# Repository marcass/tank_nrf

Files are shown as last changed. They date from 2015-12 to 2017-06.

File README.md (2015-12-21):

# tank_nrf
Arduino, NRF and ultrasonic sensors

Resources:
* http://tmrh20.github.io/RF24Mesh/
* http://www.mysensors.org/
* https://bitbucket.org/teckel12/arduino-new-ping/wiki/Home
* http://www.gammon.com.au/forum/?id=12821 this is paowering using a capacitor/solar panel

Hardware:
* http://www.aliexpress.com/item/SINMAX-8dBi-Wifi-Antenna-IEEE-802-11b-g-Indoor-Parabolic-Antenna-2-4GHz-High-Gain-USB/848558663.html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,searchweb201644_3_79_78_77_82_80_62,searchweb201560_5
* nrf modules like NRF24L01+PA+LNA
* http://www.aliexpress.com/item/J34-Free-Shipping-DC-5V-Ultrasonic-Module-Distance-Measuring-Transducer-Sensor-Perfect-Waterproof/32400424410.html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,searchweb201644_3_79_78_77_82_80_62,searchweb201560_5

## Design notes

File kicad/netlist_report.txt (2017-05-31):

Info: Reading netlist file "/home/mw/Dropbox/tank_nrf/tank_nrf.net".

Info: Using references to match components and footprints.

Error: Component 'IC1' footprint 'QFN_MLF20' was not found in any libraries in the footprint library table.

Error: Component 'S1' footprint 'MODULE' was not found in any libraries in the footprint library table.

Error: Component 'U3' footprint 'MODULE' was not found in any libraries in the footprint library table.

Error: Component 'U1' footprint 'DIL20' was not found in any libraries in the footprint library table.

Error: No footprint defined for component 'D2'.

Error: No footprint defined for component 'C6'.

Error: No footprint defined for component 'Q1'.

Error: No footprint defined for component 'R3'.

Error: No footprint defined for component 'R4'.

Error: No footprint defined for component 'R2'.

Error: No footprint defined for component 'C5'.

Error: No footprint defined for component 'C4'.

Error: No footprint defined for component 'D3'.

Error: No footprint defined for component 'D1'.

Error: No footprint defined for component 'R1'.

Error: No footprint defined for component 'U2'.

Error: No footprint defined for component 'C3'.

Error: No footprint defined for component 'C2'.

Error: No footprint defined for component 'C1'.

Info: Checking netlist component footprint "C1:/58072D95:".

Error: Cannot add new component "C1:/58072D95" due to missing footprint "".

Info: Checking netlist component footprint "C2:/58072F63:".

Error: Cannot add new component "C2:/58072F63" due to missing footprint "".

Info: Checking netlist component footprint "C3:/580730B1:".

Error: Cannot add new component "C3:/580730B1" due to missing footprint "".

Info: Checking netlist component footprint "C4:/580804F8:".

Error: Cannot add new component "C4:/580804F8" due to missing footprint "".

Info: Checking netlist component footprint "C5:/58080AA5:".

Error: Cannot add new component "C5:/58080AA5" due to missing footprint "".

Info: Checking netlist component footprint "C6:/5808138D:".

Error: Cannot add new component "C6:/5808138D" due to missing footprint "".

Info: Checking netlist component footprint "D1:/5807FD29:".

Error: Cannot add new component "D1:/5807FD29" due to missing footprint "".

Info: Checking netlist component footprint "D2:/5807FDC4:".

Error: Cannot add new component "D2:/5807FDC4" due to missing footprint "".

Info: Checking netlist component footprint "D3:/58080422:".

Error: Cannot add new component "D3:/58080422" due to missing footprint "".

Info: Checking netlist component footprint "IC1:/58080884:QFN_MLF20".

Error: Cannot add new component "IC1:/58080884" due to missing footprint "QFN_MLF20".

Info: Checking netlist component footprint "Q1:/58081893:".

Error: Cannot add new component "Q1:/58081893" due to missing footprint "".

Info: Checking netlist component footprint "R1:/5807FCB2:".

Error: Cannot add new component "R1:/5807FCB2" due to missing footprint "".

Info: Checking netlist component footprint "R2:/58080B65:".

Error: Cannot add new component "R2:/58080B65" due to missing footprint "".

Info: Checking netlist component footprint "R3:/580816BC:".

Error: Cannot add new component "R3:/580816BC" due to missing footprint "".

Info: Checking netlist component footprint "R4:/5808161B:".

Error: Cannot add new component "R4:/5808161B" due to missing footprint "".

Info: Checking netlist component footprint "S1:/580734B0:MODULE".

Error: Cannot add new component "S1:/580734B0" due to missing footprint "MODULE".

Info: Checking netlist component footprint "U1:/58072C84:DIL20".

Error: Cannot add new component "U1:/58072C84" due to missing footprint "DIL20".

Info: Checking netlist component footprint "U2:/58073E5F:".

Error: Cannot add new component "U2:/58073E5F" due to missing footprint "".

Info: Checking netlist component footprint "U3:/580738E6:MODULE".

Error: Cannot add new component "U3:/580738E6" due to missing footprint "MODULE".

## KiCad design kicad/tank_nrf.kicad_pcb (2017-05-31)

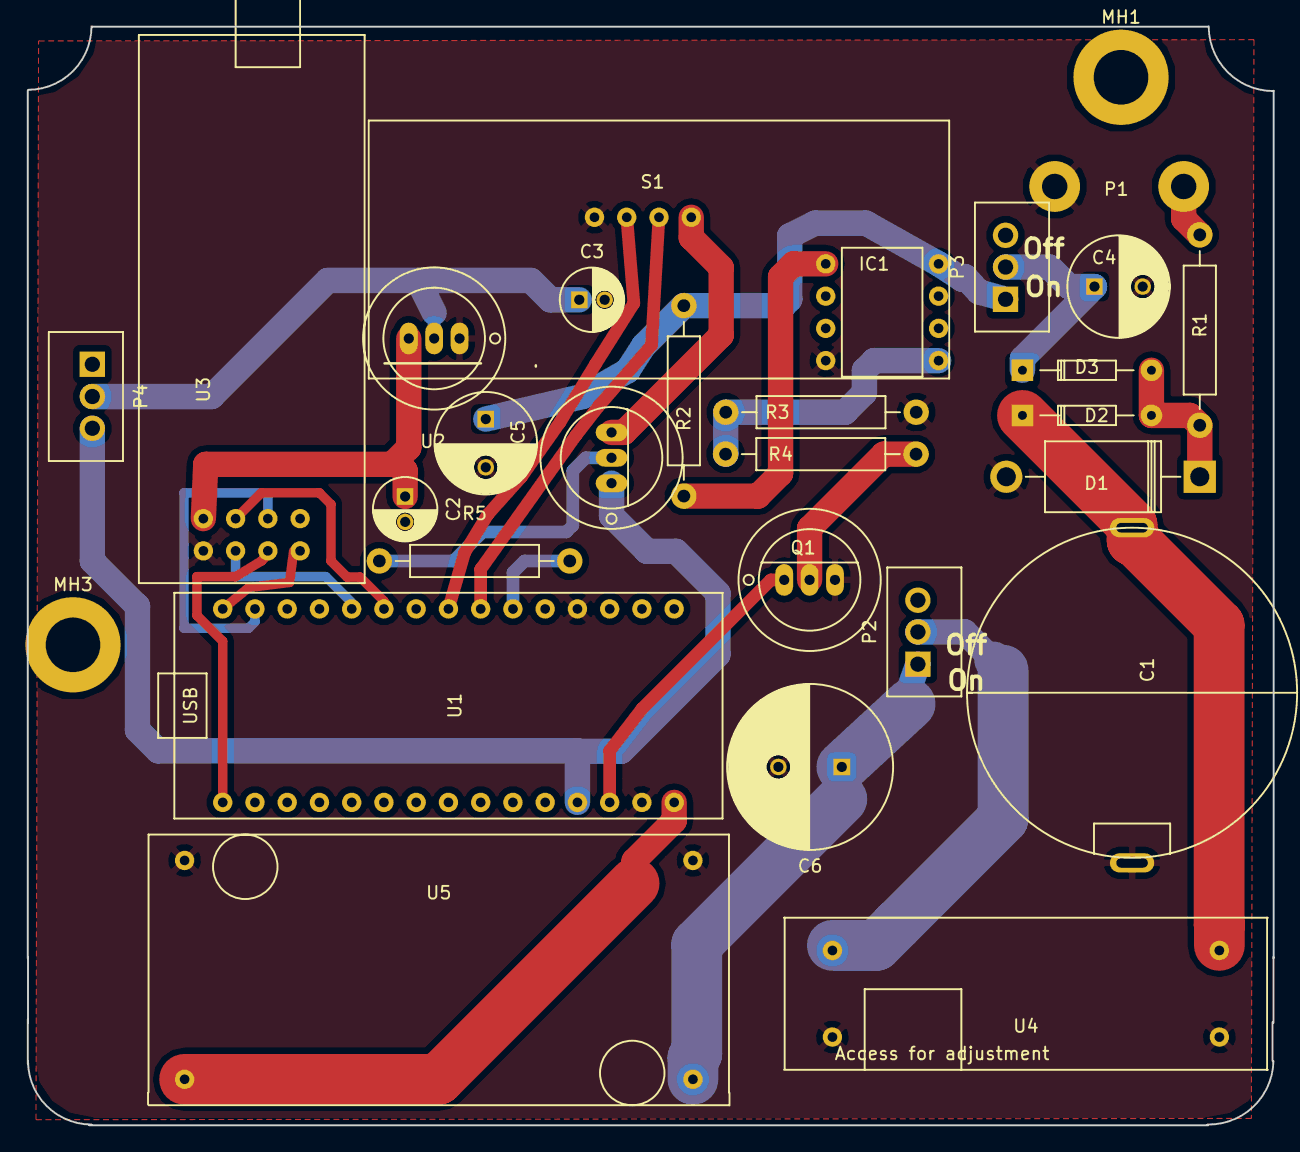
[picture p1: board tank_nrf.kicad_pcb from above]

Board: 2 copper layers, 98.1 x 86.6 mm, 29 parts (0 on the bottom side), 26 nets.

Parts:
C1: 4F; 4FCap
C2, C3: 1muF; C_Radial_D5_L11_P2
C4: 440muF; C_Radial_D8_L21_P3.8
C5: 440uF; C_Radial_D8_L13_P3.8
C6: 2F; C_Radial_D13_L21_P5
D1: 1N5817 (prev IN752); Diode_DO-201AD_Horizontal_RM15
D2, D3: IN4148; Diode_DO-35_SOD27_Horizontal_RM10
IC1: ATTINY25-SS; ATTiny85
MH1, MH3: CONN_01X01; MountingHole_4.3mm_M4_DIN965_Pad
P1: CONN_01X02; WireConnection_2.00mmDrill
P2: Jumper1; Wafer_Vertical10x5.8x7RM2.5-3
P3: Jumper2; Wafer_Vertical10x5.8x7RM2.5-3
P4: Jumper3; Wafer_Vertical10x5.8x7RM2.5-3
Q1: 2N7000
Q3: PN2222A; OldSowjetaera_Transistor_Type-I_BigPads
R1: 220; Resistor_Horizontal_RM15mm
R2, R3: 10k; Resistor_Horizontal_RM15mm
R4: 150; Resistor_Horizontal_RM15mm
R5: 470; Resistor_Horizontal_RM15mm
S1: JSN-SR40T; JSN-SR04T
U1: arduino_nano (mini?); ArduinoNano
U2: MCP1700T-3002E/TT; OldSowjetaera_Transistor_Type-I_BigPads
U3: nRF24L01+; nrf
U4: MT3608b; MT3608
U5: LM2596b; LM2596

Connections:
+5V: P4.3, Q3.1, U1.12
ATtiny5V: C5.1, IC1.8, P3.1, R2.2
CE: U1.26, U3.3
CS: U1.25, U3.4
Echo: S1.3, U1.23
GND: C1.2, C2.2, C3.2, C4.2, C5.2, C6.2, D1.2, IC1.4, P1.1, Q1.2, R3.2, S1.4, U1.14, U1.19, U2.1, U3.1, U4.2, U4.3, U5.2, U5.3
LM2596+: U1.15, U5.4
MISO: U1.30, U3.7
MOSI: U1.29, U3.6
NanoReset: Q1.3, U1.13
unnamed: C2.1, U2.3, U3.2
unnamed: C3.1, P4.2, U2.2
unnamed: C4.1, D3.1, P3.2
unnamed: C6.1, P2.1, U5.1
unnamed: D1.1, D2.2, D3.2, R1.2
unnamed: IC1.1, R2.1
unnamed: IC1.5, R3.1, R4.2
unnamed: P2.2, U4.4
unnamed: Q1.1, R4.1
unnamed: Q3.2, R5.1
unnamed: Q3.3, S1.1
SCK: U1.1, U3.5
Trig: S1.2, U1.22
echo_trans: R5.2, U1.21
solarpanel+: P1.2, R1.1
stepupmt3608+: C1.1, D2.1, U4.1

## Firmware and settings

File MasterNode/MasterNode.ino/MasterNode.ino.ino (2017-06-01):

 
 
 /** RF24Mesh_Example_Master.ino by TMRh20
  * 
  *
  * This example sketch shows how to manually configure a node via RF24Mesh as a master node, which
  * will receive all data from sensor nodes.
  *
  * The nodes can change physical or logical position in the network, and reconnect through different
  * routing nodes as required. The master node manages the address assignments for the individual nodes
  * in a manner similar to DHCP.
  *
  */



  
#include "RF24Network.h"
#include "RF24.h"
#include "RF24Mesh.h"
#include <SPI.h>
//Include eeprom.h for AVR (Uno, Nano) etc. except ATTiny
#include <EEPROM.h>

/***** Configure the chosen CE,CS pins *****/
RF24 radio(8,7);
RF24Network network(radio);
RF24Mesh mesh(radio,network);

uint32_t displayTimer = 0;
int ID = 0;

/**************************************************
 * Configure the sensor array for sensible messaging to myController
 * 
 * Tank detail can be viewd here: https://paper.dropbox.com/doc/Arduino-Water-Tank-Level-kHoAXxvG9oPQK7naydd9i
 * Name              |Tank no.| Sensor
 * ==============================================================
 * Top tank          | 1      | Y
 * Noel's Break tank | 2      | Y
 * Sal's Bush   tank | 3      | Y
 * Yards             | 4      | N
 * Home hill         | 5      | N
 * Home              | 0      | N
 */

const int TOP = 1;
const int NOEL = 2;
const int SAL = 3;
const int SENS = 3;
int node_id;
// presentation described here: https://www.mysensors.org/download/serial_api_20
String present = ";1;0;0;15";

void setup() {
  Serial.begin(115200);

  // Set the nodeID to 0 for the master node
  mesh.setNodeID(0);
  Serial.println(mesh.getNodeID());
  // Connect to the mesh
  mesh.begin();
  //present sensors to MyController
  int sensors[] = {TOP, NOEL, SAL};
  for (int n = 0; n < SENS; n++) {
    node_id = sensors[n];
    String present_node = (node_id + present);
    Serial.println(present_node);
  }

}


void loop() {    

  // Call mesh.update to keep the network updated
  mesh.update();
  
  // In addition, keep the 'DHCP service' running on the master node so addresses will
  // be assigned to the sensor nodes
  mesh.DHCP();
  
  
  // Check for incoming data from the sensors
  if(network.available()){
    RF24NetworkHeader header;
    network.peek(header);
    
    uint32_t dat=0;
    switch(header.type){
      // Display the incoming millis() values from the sensor nodes
      case 'M': 
        network.read(header,&dat,sizeof(dat)); 
//        Serial.print("Node id is ");
//        Serial.println(mesh.getNodeID(header.from_node));
        Serial.print(mesh.getNodeID(header.from_node));
        //set,req described here: https://www.mysensors.org/download/serial_api_20
        Serial.print(";1;1;1;13;"); // = "SENSOR_ID";"COMMAND (update value)";"ACK (this is an ack message);"TYPE" (distance);
        Serial.println(dat);//payload
        break;
      default: 
        network.read(header,0,0); 
        Serial.println(header.type);
        break;
    }
  }
  
  if(millis() - displayTimer > 5000){
    displayTimer = millis();
    Serial.println(" ");
    Serial.println(F("********Assigned Addresses********"));
     for(int i=0; i<mesh.addrListTop; i++){
       Serial.print("NodeID: ");
       Serial.print(mesh.addrList[i].nodeID);
       Serial.print(" RF24Network Address: 0");
       Serial.println(mesh.addrList[i].address,OCT);
     }
    Serial.println(F("**********************************"));
  }
}

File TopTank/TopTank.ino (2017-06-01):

/** RF24Mesh_Example.ino by TMRh20
 *
 * This example sketch shows how to manually configure a node via RF24Mesh, and send data to the
 * master node.
 * The nodes will refresh their network address as soon as a single write fails. This allows the
 * nodes to change position in relation to each other and the master node.
 */


#include "RF24.h"
#include "RF24Network.h"
#include "RF24Mesh.h"
#include <SPI.h>
#include <EEPROM.h>
//#include <printf.h>

//Sonar stuff
#include <NewPing.h>

#define TRIGGER_PIN  4  // Arduino pin tied to trigger pin on the ultrasonic sensor.
#define ECHO_PIN     5  // Arduino pin tied to echo pin on the ultrasonic sensor.
#define MAX_DISTANCE 400 // Maximum distance we want to ping for (in centimeters). Maximum sensor distance is rated at 400-500cm.
int POWER = 3;
int distance;
const int READ_INTERVAL = 2000;
long prev_millis = 0;

NewPing sonar(TRIGGER_PIN, ECHO_PIN, MAX_DISTANCE); // NewPing setup of pins and maximum distance.


/**** Configure the nrf24l01 CE and CS pins ****/
RF24 radio(8,7);
RF24Network network(radio);
RF24Mesh mesh(radio, network);

/**
 * User Configuration: nodeID - A unique identifier for each radio. Allows addressing
 * to change dynamically with physical changes to the mesh.
 *
 * In this example, configuration takes place below, prior to uploading the sketch to the device
 * A unique value from 1-255 must be configured for each node.
 * This will be stored in EEPROM on AVR devices, so remains persistent between further uploads, loss of power, etc.
 *
 **/
#define nodeID 1 //top tank

struct payload_t {
  unsigned long ms;
  unsigned long counter;
};

void setup() {

  Serial.begin(115200);
  //printf_begin();
  // Set the nodeID manually
  mesh.setNodeID(nodeID);
  // Connect to the mesh
  Serial.println(F("Connecting to the mesh..."));
  mesh.begin();
  pinMode(POWER, OUTPUT);
  digitalWrite(POWER, LOW);
}

void measure() {
  digitalWrite(POWER, HIGH);
  delay(1000);
  distance = sonar.ping_cm();
  digitalWrite(POWER, LOW);
}

void loop() {

  mesh.update();

  // Read distance and send to master
  if (millis() - prev_millis > READ_INTERVAL) {
    prev_millis = millis();
    measure();
    // Send an 'M' type message containing the distance
    if (!mesh.write(&distance, 'M', sizeof(distance))) {

      // If a write fails, check connectivity to the mesh network
      if ( ! mesh.checkConnection() ) {
        //refresh the network address
        Serial.println("Renewing Address");
        mesh.renewAddress();
      } else {
        Serial.println("Send fail, Test OK");
      }
    } else {
      Serial.print("Send OK: "); 
      Serial.print(distance);
      Serial.println("cm");
    }
  }

  while (network.available()) {
    RF24NetworkHeader header;
    payload_t payload;
    network.read(header, &payload, sizeof(payload));
    Serial.print("Received packet #");
    Serial.print(payload.counter);
    Serial.print(" at ");
    Serial.println(payload.ms);
  }
}

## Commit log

2015-12-21 Update README.md
    Power options
2016-11-02 added brownout control courtesy of nick gammon
    [ATTiny_brownout.ino]
2016-12-05 optimise for powering up pin when u/s module needed
2017-05-31 added kicad, started on setup
    [tank_nrf.kicad_pcb, tank_nrf.sch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]
